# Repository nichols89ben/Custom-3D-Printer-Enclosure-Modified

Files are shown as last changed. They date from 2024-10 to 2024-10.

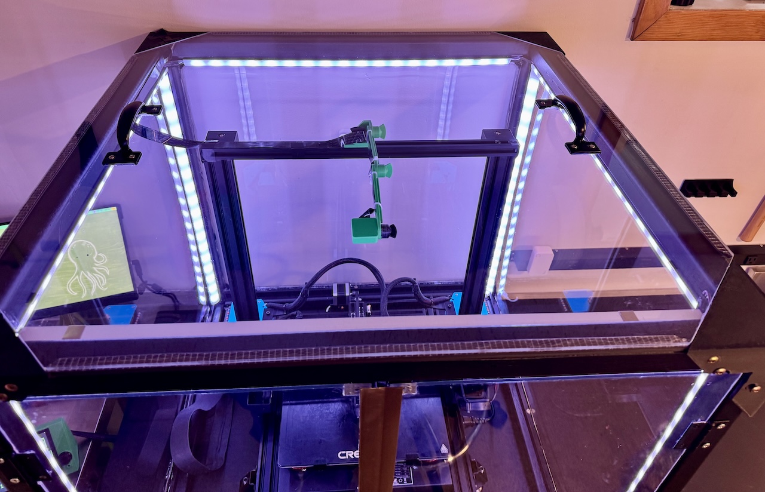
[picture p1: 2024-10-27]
Build Pictures/3D Printer Case Top.jpeg

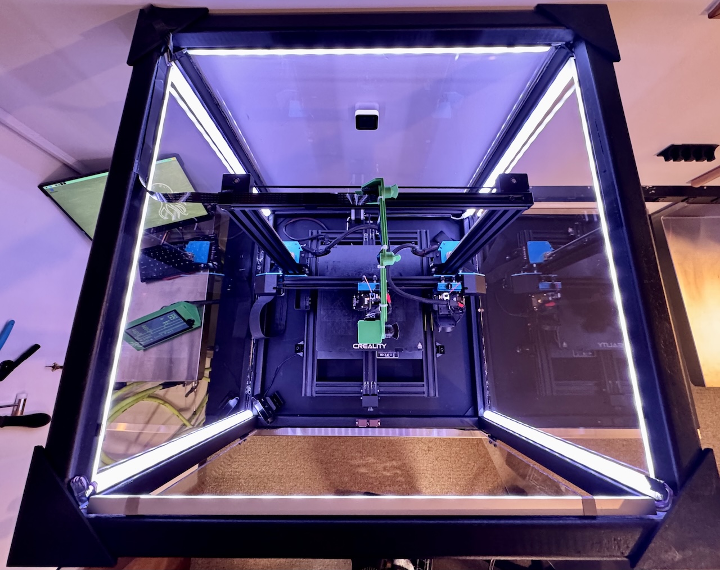
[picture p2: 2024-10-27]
Build Pictures/3D Printer Case Top 3.jpeg

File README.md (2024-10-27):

# Custom Enclosure Modifications for SV04 IDEX 3D Printer

### Printer Frame Dimensions
- **653mm x 625mm x 650mm** (29in x 29in x 28in)

This enclosure was modified from an original design to accommodate my larger printer. I documented the enclosure dimensions, wood and plexiglass resources in the US, and included build pictures, 3D files, and a bill of materials for wood and plexiglass cuts.

### Modifications

- **Frame Adjustment**: Increased frame size to fit the larger printer, using affordable wood square-end balusters.
  
- **Doors and Side Panels**: Used 3mm (1/8") pre-cut plexiglass sheets (36" x 24"). Larger sizes were special-order and costly, so I opted for easy-to-find sizes that only required one straight cut.

- **Gap Frame for Plexiglass**: Added 1/2"x1/2" square dowels to the frame for plexiglass support, as the sheets left a 1-inch gap in each window.

- **Resized Corner Connectors**: Enlarged connectors for the bigger frame, with front connectors modified to fit the door. Each corner slightly overlaps the frame, providing additional plexiglass support.

- **Plexiglass Attachment**: Used Liquid Nails for secure attachment; no clamps needed, and one tube was sufficient for all panels.

- **Lid Panel**: Used a 1/4" plexiglass sheet (30"x36") for the lid, which added stability. For cutting, I scored with a plexiglass knife and finished with a Dremel and diamond wheel, then polished with 400-grit sandpaper.

- **Lid Handles and Seal**: Added utility handles for easy lid removal and a rubber gasket for a better seal and to protect the wood.

- **Magnetic Door Closers**: Added cabinet magnets to keep the doors shut, plus a door sweep to seal the door gap if cuts aren't precise.

- **Utility Hinges**: Replaced 3D-printed hinges with affordable utility hinges and door knobs.

- **Enhanced LED Lighting**: Installed a full roll of LED strips along most edges for extra lighting.

If you need any clarification, feel free to reach out.

### Credit
All credit to the original designer:  
- [David McDaid’s Blog Post](https://davidmcdaid.wordpress.com/2023/01/30/custom-enclosure-for-3d-printer/)  
- [GitHub Repository](https://github.com/daveydaid/Custom-3DPrinter-Enclosure)

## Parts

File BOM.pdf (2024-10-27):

Part Number Thumbnail image Quantity | Name | Description Width Height Length Item | Links
F-0022 | 2 | Plexiglass Doors | 3mm Thick 0.079 | 12.5 | 24.75
1/8" Thick Plexiglass Sheets - 36" x 24" | https://www.amazon.com/dp/B0BHQXNQD4?th=1
F-0050 | 3 | Plexiglass Panels | 3mm Thick 0.079 | 24 | 26
1/8" Thick Plexiglass Sheets - 36" x 24" | https://www.amazon.com/dp/B0BHQXNQD4?th=1
F-0049 | 1 | Plexiglass Lid | 3mm Thick 0.079 | 29 | 29

30 in. x 36 in. x 0.220 (1/4) in. Clear Acrylic Sheet
(I used 1/4inch, if you can find 1/8 (3mm) use that) | https://www.homedepot.com/p/OPTIX-30-in-x-36-in-x-0-220-1-4-in-Clear-Acrylic-Sheet-MC-22/202038052
F-0037 | 4 | Top Wood Frame | 1.5 | 1.5 | 26

36 in. x 2 in. Pine Wood Square End Baluster
(It says 2inch but its actuall 1.5 inch) | https://www.homedepot.com/p/36-in-x-2-in-Pressure-Treated-Southern-Yellow-Pine-Wood-Square-End-Baluster-102596/202297458
F-0023 | 4 | Wood Pillars | 1.5 | 1.5 | 28

36 in. x 2 in. Pine Wood Square End Baluster
(It says 2inch but its actuall 1.5 inch) | https://www.homedepot.com/p/36-in-x-2-in-Pressure-Treated-Southern-Yellow-Pine-Wood-Square-End-Baluster-102596/202297458
F-0038 | 4 | Bottom Wood Frame | 1.5 | 1.5 | 26

36 in. x 2 in. Pine Wood Square End Baluster
(It says 2inch but its actuall 1.5 inch) | https://www.homedepot.com/p/36-in-x-2-in-Pressure-Treated-Southern-Yellow-Pine-Wood-Square-End-Baluster-102596/202297458
F-0028 | 6 | Wood Plexiglass Gap Frame | 0.5 | 0.5 | 26
Hardwood Square Dowel - 36 in. x 0.5 in | https://www.homedepot.com/p/Waddell-Hardwood-Square-Dowel-36-in-x-0-5-in-Sanded-and-Ready-for-Finishing-Versatile-Wooden-Rod-for-DIY-Home-Projects-8308U/100547367
F-0052 | 4 | Front PLA Connectors | 4.3 | 4.3 | 4.3
F-0030 | 4 | Back PLA Connectors | 3 | 4.3 | 6

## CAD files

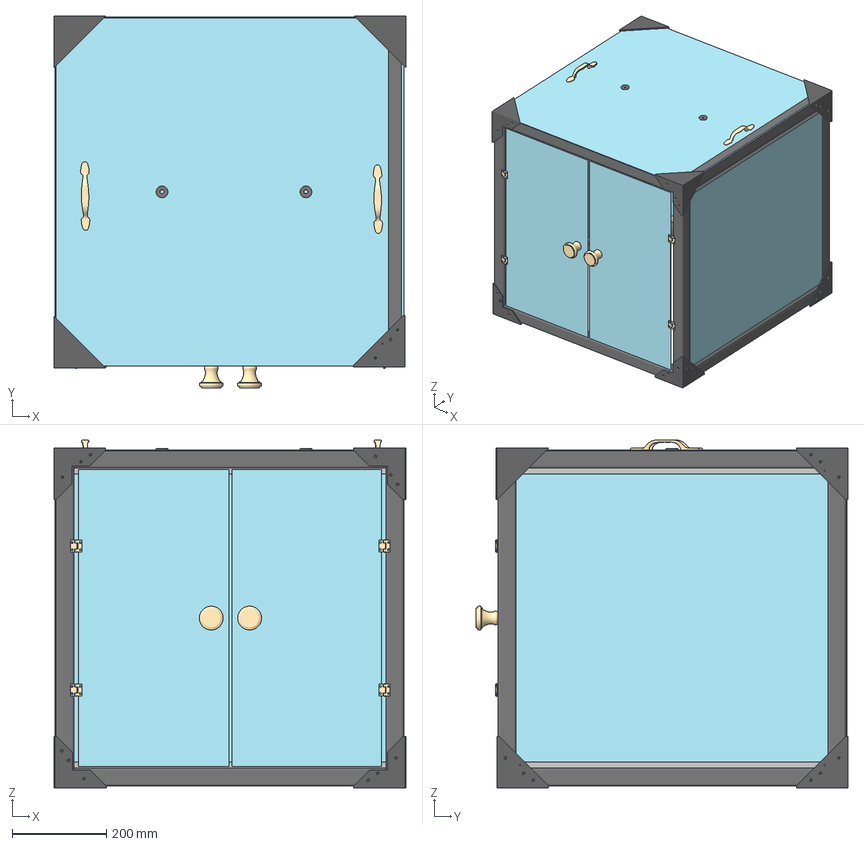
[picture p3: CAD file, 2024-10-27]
3D Models/3D_Printer_Case_v3_Render.3mf
745.0 x 787.8 x 736.7 mm
BACK_Bottom Left Connector
BACK_Bottom Right Connector
BACK_LEFT_Pillar
BACK_Panel
BACK_RIGHT_Pillar
BACK_Top Left Connector
BACK_Top Right Connector
BACK_Top_Frame
BACK_btm_Frame
BACK_btm_GAP_Frame
BACK_top_GAP_Frame
FRONT_Bottom Left Connector
FRONT_Bottom Right Connector
FRONT_LED_Diffuser (1) (1) (1) (1)
FRONT_LED_Diffuser (1) (1) (1)
FRONT_LED_Diffuser (1) (1)
FRONT_LED_Diffuser (1)
FRONT_LEFT_Pillar
FRONT_RIGHT_Pillar
FRONT_Top Right Connector
FRONT_Top_Frame
FRONT_Top_Left Connector
FRONT_btm_Frame
Handle 2
Handle1
LEFT_Door
LEFT_Panel
LEFT_Top_Frame
LEFT_btm_Frame
LEFT_btm_GAP_Frame
LEFT_top_GAP_Frame
LID_Filament_Hole (1) (2)
LID_Filament_Hole (1)
Left Knob
RIGHT_Door
RIGHT_Panel
RIGHT_Top_Frame
RIGHT_btm_Frame
RIGHT_btm_GAP_Frame
RIGHT_top_GAP_Frame
Right Knob
TOP_Lid

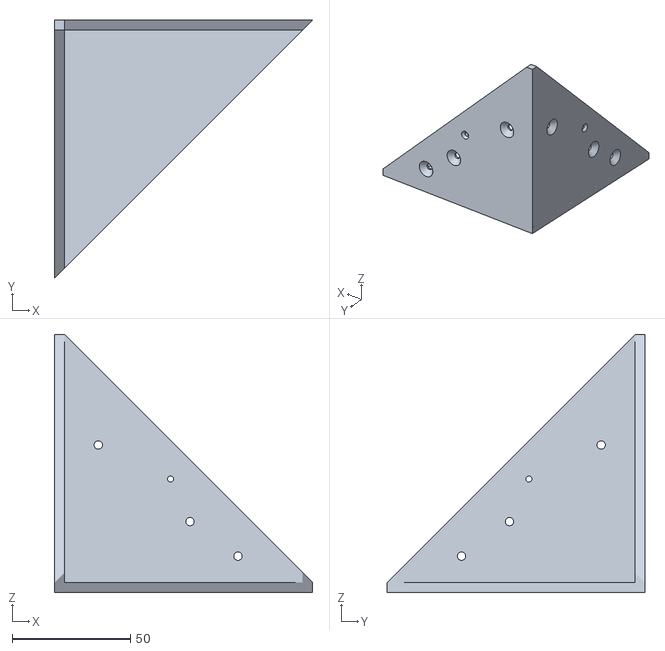
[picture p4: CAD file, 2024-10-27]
STL Connectors/3D_Printer_Case_Back_Connector.stl
109.2 x 109.2 x 109.2

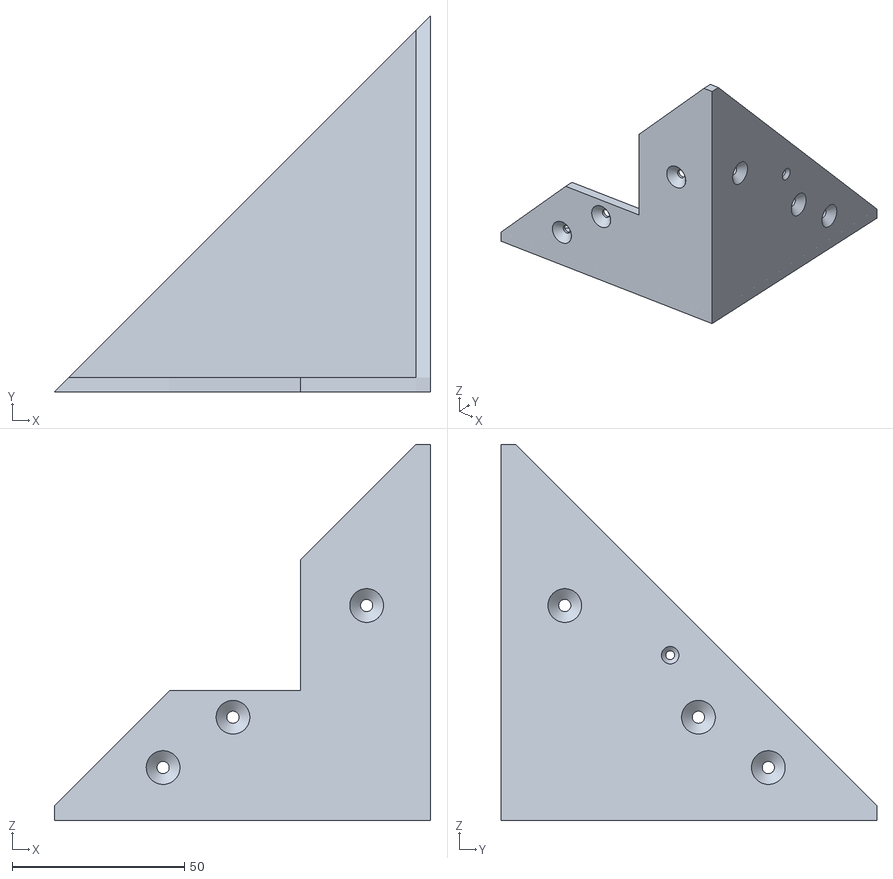
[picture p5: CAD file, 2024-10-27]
STL Connectors/3D_Printer_Case_Front_Connector.stl
109.2 x 109.2 x 109.2

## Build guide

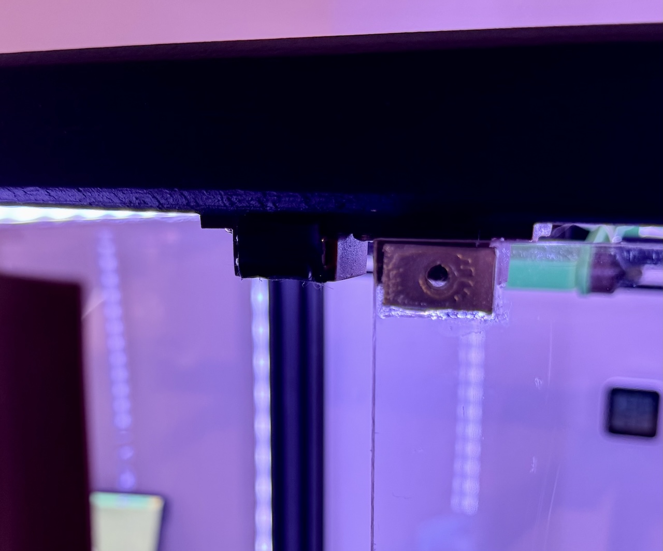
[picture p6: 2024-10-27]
Build Pictures/3D Printer Case Door Magnet.jpeg

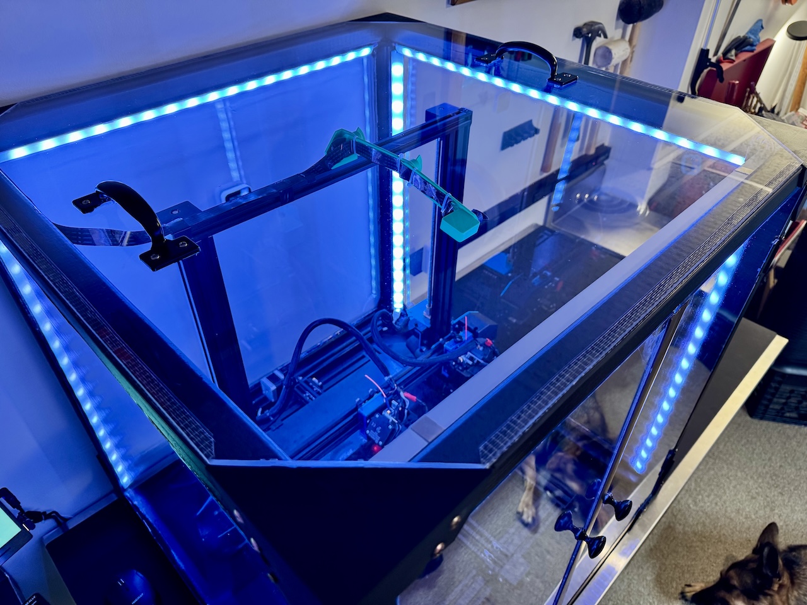
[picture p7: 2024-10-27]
Build Pictures/3D Printer Case Top 2.jpeg

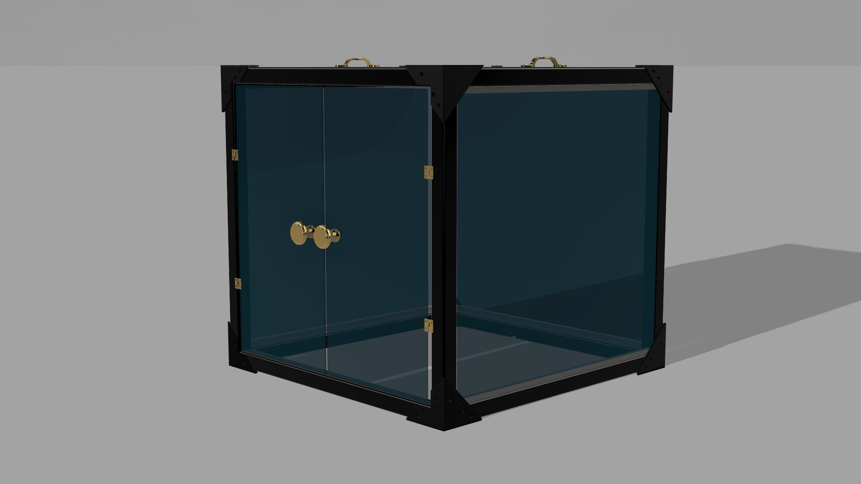
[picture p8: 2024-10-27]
3D Renders/3D_Printer_Case_Render Right Side.png

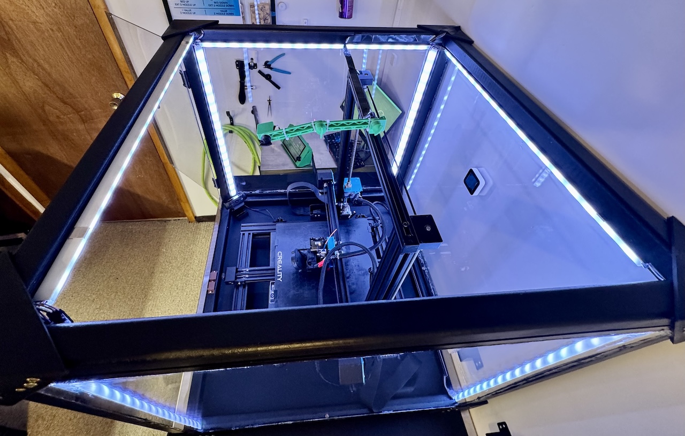
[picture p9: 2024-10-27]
Build Pictures/3D Printer Case Top 4.jpeg
